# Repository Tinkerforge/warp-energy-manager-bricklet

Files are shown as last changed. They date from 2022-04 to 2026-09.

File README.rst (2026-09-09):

WARP Energy Manager Bricklet
============================

This Bricklet together with the ESP32 Ethernet Brick form the
hardware used in the WARP Energy Manager.

See https://www.warp-charger.com/energy-manager.html for more details

This repository contains the firmware source code and the hardware design
files. The documentation generator configs can be found at
https://github.com/Tinkerforge/generators

.. BEGIN WARP REPOSITORIES (managed block, generated from esp32-firmware/repo_overview.rst - do not edit by hand, run update_repo_overview.py instead)

WARP Repositories
-----------------

This is an overview of all repositories that make up the WARP Charger and
WARP Energy Manager ecosystem.

Please report **any** issue concerning WARP hard- or software in the
`esp32-firmware`_ repository, no matter which repository it originates from.

Software
~~~~~~~~

- `esp32-firmware`_ - Source code of the ESP32 firmware shared between all WARP Chargers and Energy Managers

Libraries used by the firmware:

- `tfjson`_ - SAX style JSON serializer and deserializer
- `tfnetwork`_ - Modbus TCP server and client implementation
- `tfocpp`_ - OCPP 1.6 implementation
- `tftools`_ - Miscellaneous tools and helpers

Remote access:

- `esp32-remote-access`_ - Source code of the my.warp-charger.com remote access server

Documentation, tools and integrations:

- `warp-charger`_ - Source code of (docs.)warp-charger.com and the printed manual, released firmwares, datasheets and documents, as well as some tools and hardware design files
- `api.warp-charger.com`_ - Serves APIs that are used by WARP Chargers to obtain relevant public information like day ahead prices
- `vislog.warp-charger.com`_ - Visualizes WARP Charger logs and EVSE debug protocols
- `dbus-warp-charger`_ - Integrates WARP Chargers into a Victron Energy Venus OS device (e.g. Cerbo GX)

WARP Charger Hardware
~~~~~~~~~~~~~~~~~~~~~~

WARP4 Charger
"""""""""""""

*Current charger generation.*

- `warp-esp32-ethernet-v2-brick`_ - Hardware design files of the WARP ESP32 Ethernet Brick 2.0
- `warp-esp32-ethernet-v2-co-bricklet`_ - Firmware source code of the WARP ESP32 Ethernet 2.0 Co Bricklet (co-processor)
- `evse-v4-bricklet`_ - Hardware design files of the EVSE 4.0 Bricklet (firmware shared with the EVSE 2.0 Bricklet)
- `nfc-bricklet`_ - Firmware source code and hardware design files of the NFC Bricklet

WARP3 Charger
"""""""""""""

- `warp-esp32-ethernet-brick`_ - Hardware design files of the WARP ESP32 Ethernet Brick
- `evse-v3-bricklet`_ - Hardware design files of the EVSE 3.0 Bricklet (firmware shared with the EVSE 2.0 Bricklet)
- `nfc-bricklet`_ - Firmware source code and hardware design files of the NFC Bricklet

WARP2 Charger
"""""""""""""

- `esp32-ethernet-brick`_ - Hardware design files of the ESP32 Ethernet Brick
- `evse-v2-bricklet`_ - Firmware source code and hardware design files of the EVSE 2.0 Bricklet
- `nfc-bricklet`_ - Firmware source code and hardware design files of the NFC Bricklet

WARP1 Charger
"""""""""""""

- `esp32-brick`_ - Hardware design files of the ESP32 Brick
- `evse-bricklet`_ - Firmware source code and hardware design files of the EVSE Bricklet
- `rs485-bricklet`_ - Firmware source code and hardware design files of the RS485 Bricklet

WARP Energy Manager Hardware
~~~~~~~~~~~~~~~~~~~~~~~~~~~~~~

WARP Energy Manager 2.0
"""""""""""""""""""""""

*Current energy manager generation.*

- `esp32-ethernet-brick`_ - Hardware design files of the ESP32 Ethernet Brick
- `warp-energy-manager-v2-bricklet`_ - Firmware source code and hardware design files of the WARP Energy Manager 2.0 Bricklet
- `warp-front-panel-bricklet`_ - Firmware source code and hardware design files of the WARP Front Panel Bricklet

WARP Energy Manager 1.0
"""""""""""""""""""""""

- `esp32-ethernet-brick`_ - Hardware design files of the ESP32 Ethernet Brick
- `warp-energy-manager-bricklet`_ - Firmware source code and hardware design files of the WARP Energy Manager Bricklet

Forked/patched projects
~~~~~~~~~~~~~~~~~~~~~~~~~

- `arduino-esp32`_
- `esp32-arduino-libs`_
- `WireGuard-ESP32-Arduino`_

.. Link targets: One definition per repository, keep in sync with the lists above.

.. _esp32-firmware: https://github.com/Tinkerforge/esp32-firmware
.. _tfjson: https://github.com/Tinkerforge/tfjson
.. _tfnetwork: https://github.com/Tinkerforge/tfnetwork
.. _tfocpp: https://github.com/Tinkerforge/tfocpp
.. _tftools: https://github.com/Tinkerforge/tftools
.. _esp32-remote-access: https://github.com/Tinkerforge/esp32-remote-access
.. _warp-charger: https://github.com/Tinkerforge/warp-charger
.. _api.warp-charger.com: https://github.com/Tinkerforge/api.warp-charger.com
.. _vislog.warp-charger.com: https://github.com/Tinkerforge/vislog.warp-charger.com
.. _dbus-warp-charger: https://github.com/Tinkerforge/dbus-warp-charger
.. _warp-esp32-ethernet-v2-brick: https://github.com/Tinkerforge/warp-esp32-ethernet-v2-brick
.. _warp-esp32-ethernet-v2-co-bricklet: https://github.com/Tinkerforge/warp-esp32-ethernet-v2-co-bricklet
.. _evse-v4-bricklet: https://github.com/Tinkerforge/evse-v4-bricklet
.. _nfc-bricklet: https://github.com/Tinkerforge/nfc-bricklet
.. _warp-esp32-ethernet-brick: https://github.com/Tinkerforge/warp-esp32-ethernet-brick
.. _evse-v3-bricklet: https://github.com/Tinkerforge/evse-v3-bricklet
.. _esp32-ethernet-brick: https://github.com/Tinkerforge/esp32-ethernet-brick
.. _evse-v2-bricklet: https://github.com/Tinkerforge/evse-v2-bricklet
.. _esp32-brick: https://github.com/Tinkerforge/esp32-brick
.. _evse-bricklet: https://github.com/Tinkerforge/evse-bricklet
.. _rs485-bricklet: https://github.com/Tinkerforge/rs485-bricklet
.. _warp-energy-manager-v2-bricklet: https://github.com/Tinkerforge/warp-energy-manager-v2-bricklet
.. _warp-front-panel-bricklet: https://github.com/Tinkerforge/warp-front-panel-bricklet
.. _warp-energy-manager-bricklet: https://github.com/Tinkerforge/warp-energy-manager-bricklet
.. _arduino-esp32: https://github.com/Tinkerforge/arduino-esp32
.. _esp32-arduino-libs: https://github.com/Tinkerforge/esp32-arduino-libs
.. _WireGuard-ESP32-Arduino: https://github.com/Tinkerforge/WireGuard-ESP32-Arduino

.. END WARP REPOSITORIES

Repository Content
------------------

software/:
 * examples/: Examples for all supported languages
 * build/: Compiled files
 * src/: Source code of firmware
 * Makefile: Makefile to build project

hardware/:
 * Contains KiCad project files and additionally schematics as PDF

datasheets/:
 * Contains datasheets for sensors and complex ICs that are used

Hardware
--------

The hardware is designed with the open source EDA Suite KiCad
(http://www.kicad.org). Before you are able to open the files,
you have to install the Tinkerforge kicad-libraries
(https://github.com/Tinkerforge/kicad-libraries). You can either clone
them directly in hardware/ or clone them in a separate folder and
symlink them into hardware/
(ln -s kicad_path/kicad-libraries project_path/hardware). After that you
can open the .pro file in hardware/ with KiCad and from there view and
modify the schematics and the PCB layout.

Software
--------

If you want to do your own Brick/Bricklet firmware development we highly
recommend that you use our build environment setup script and read the
tutorial (https://www.tinkerforge.com/en/doc/Tutorials/Tutorial_Build_Environment/Tutorial.html).

To compile the C code we recommend you to install the newest GNU Arm Embedded
Toolchain (https://launchpad.net/gcc-arm-embedded/+download).
You also need to install bricklib2 (https://github.com/Tinkerforge/bricklib2).

You can either clone it directly in software/src/ or clone it in a
separate folder and symlink it into software/src/
(ln -s bricklib_path/bricklib2 project_path/software/src/). Finally make sure to
have CMake installed (http://www.cmake.org/cmake/resources/software.html).

After that you can build the firmware by invoking make in software/.
The firmware (.zbin) can then be found in software/build/ and uploaded
with brickv (click button "Flashing" on start screen).

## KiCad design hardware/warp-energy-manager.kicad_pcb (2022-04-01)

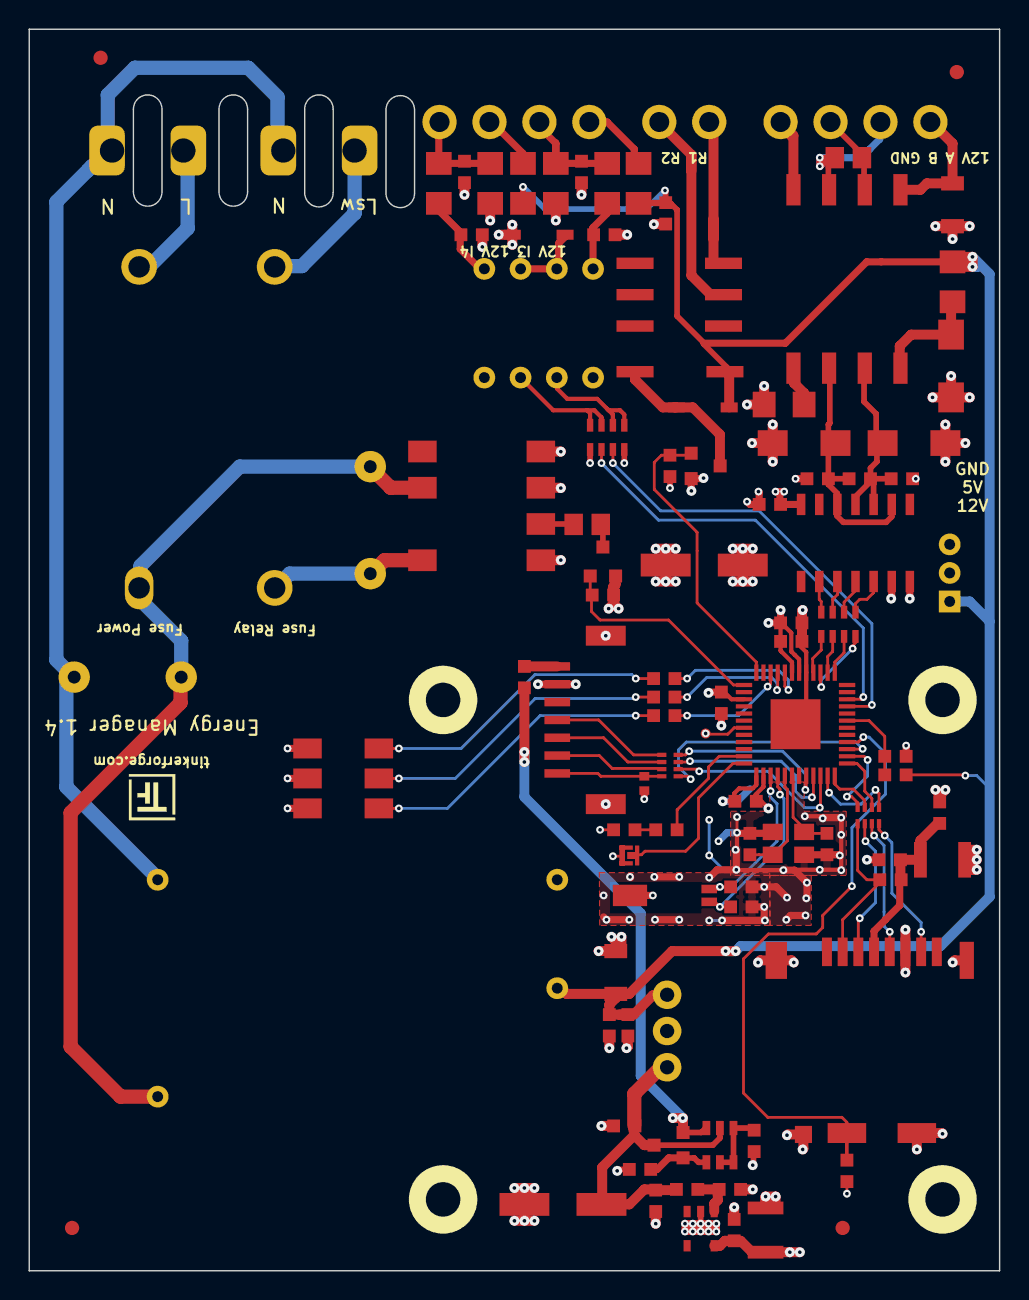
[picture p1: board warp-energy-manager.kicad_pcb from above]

Board: 4 copper layers, 68.0 x 87.0 mm, 104 parts (0 on the bottom side), 81 nets.

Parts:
A101, A102, A103, A104: DRILL; DRILL_NP_35
C101: 220pF; C0402F
C102, C104, C107, C112, C113, C114, C117, C127, C130, C132: 100nF; C0603F
C103, C106, C124, C125, C126: 1uF; C0603F
C105, C115: 4.7uF/50V; C1206
C108, C109: 100uF; ELKO_63
C110: 2.2uF; C0603F
C111, C116: 100uF; C1210
C118, C119: 15pF; C0603F
C128, C129: 10pF; C0603F
C131: 220nF; C0603F
D101: CLP6C-FKB-CK1P1G1BB7R3R3; PLCC6-6x5
D102, D106, D111: SMAJ12CA; DO-214AC
D103: blue; D0603F
D105, D107: B0520LW-7; SOD-123
F101, F102: FUSE; Fuse-Holder-5x20
Fiducial_Mark: VAL**; Fiducial_Mark
Fiducial_Mark#2, Fiducial_Mark#3, Fiducial_Mark#4: VAL**; Fiducial_Mark
J101: Boot; SolderJumper
J102: DM3CS; SD-Card-DM3CS
L101, L102, L103: FB; R0603F
L104: WE-SL
P101: CON-SENSOR2; CON-SENSOR2_180
P102: Relay; OQ_2P_5mm_230V
P103: L+N; OQ_2P_5mm_230V
P104: OUT; OQ_2P
P105: INPUT; OQ_4P
P106: DNP; JST-PH-3-THT
P110: MODBUS; OQ_4P
P111: Debug; DEBUG_PAD
PTC101, PTC102: PTC 0.45A; R1206E
Q102: SI2305CDS-T1-GE3; SOT23GDS
Q103: 2N7002P; SOT23GDS
Q105: SSM3J355R,LF; SOT23GDS
R101, R102: 51; R0603F
R103: 100; R0603F
R104, R105, R111, R112, R116, R117: 1k; R1206E
R106, R109, R140: 10k; R0603F
R107: 300k; R0603F
R108: 100k; R0603F
R113, R128: MOV-10D391KTR; VAR_10mm
R114, R137: 120; R0805E
R115, R118, R124: 1k; R0603F
R133: 47k; R0603F
R134, R136: 750; R0603F
R135: DNP; R0603F
REL101: AGQ200S12Z; AGQ2X0
RP101, RP103: 82; 4X0402
RP102: 10k; 0603X4
RP105: 10k; 4X0603
U101: XMC1404; QFN48-EP2
U103: DMMT5401; SOT26
U108: AQH3213AX; AQ-H
U109: HCPL2731; DIP-8
U110: TPS70933DBVR; SOT23-5
U111: IRM02-12; IRM02
U112: WPMDL110
U113: SP3491; SOIC-14_3.9x8.7mm_Pitch1.27mm
X101: 16MHz; CRYSTAL_3225
X102: 32.768kHz; AB26TRQ

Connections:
3V3: C102.1, C109.1, C110.1, C111.1, C127.1, C130.1, C131.1, C132.2, D101.1, D101.2, D101.3, D103.1, L102.2, Q102.S, R106.2, R115.2, R134.1, RP105.1, RP105.4, U101.18, U101.19, U101.27, U101.38, U109.8, U110.5, U113.14
5V: C103.1, C108.1, C126.1, L101.2, P106.2, Q105.D, U103.5, U112.3
485-D: RP102.4, U101.15
485-DE: RP102.3, U101.13
485-R: RP102.1, U101.16
485-~REB: RP102.2, U101.14
BOOT: J101.2, U101.36
GND: C101.2, C102.2, C103.2, C104.2, C105.2, C106.2, C107.2, C108.2, C109.2, C110.2, C111.2, C112.2, C113.1, C114.2, C115.1, C116.2, C117.2, C118.1, C119.1, C124.2, C125.2, C126.2, C127.2, C128.2, C129.2, C130.2, C131.2, C132.1, D102.1, D105.2, D106.2, D111.2, J101.1, J102.6, J102.S, P101.2, P101.EP, P106.3, PTC101.2, Q103.S, R104.2, R105.2, R108.1, R118.1, R133.1, R136.2, R140.1, U101.17, U101.37, U101.EP, U108.1, U108.3, U108.4, U109.5, U110.2, U111.4, U112.2, U113.6, U113.7, X101.3, X102.3
IN0: RP105.2, U101.9
IN1: RP105.3, U101.10
L: F101.2, R113.2, R128.1, U108.6, U111.1
N: P102.2, P103.2, R128.2, U111.2
unnamed: C101.1, P101.7, RP101.4
unnamed: C104.1, P105.2, R104.1, R112.1
unnamed: C106.1, L101.1, U110.1
unnamed: C107.1, P105.4, R105.1, R117.1
unnamed: C112.1, R117.2, U109.4
unnamed: C114.1, R112.2, U109.1
unnamed: C115.2, L104.5, P110.1
unnamed: C116.1, C117.1, J102.4, L102.1, R109.2
unnamed: C128.1, U101.41, X101.2
unnamed: C129.1, U101.42, X101.1
unnamed: D101.4, R101.1
unnamed: D101.5, R102.1
unnamed: D101.6, R103.1
unnamed: D102.2, L104.4, PTC102.2
unnamed: D103.2, R124.2
unnamed: D105.1, U109.2, U109.3
unnamed: D106.1, L104.3, R135.2, R136.1, U113.10, U113.11
unnamed: D107.1, Q103.D, REL101.8
unnamed: D111.1, L104.2, R134.2, R135.1, U113.9, U113.12
unnamed: F101.1, P103.1
unnamed: F102.1, P102.1
unnamed: F102.2, R113.1, U108.8
unnamed: J102.2, R109.1, RP103.1
unnamed: J102.3, RP103.2
unnamed: J102.5, RP103.3
unnamed: J102.7, RP103.4
unnamed: L103.1, Q105.S, U103.6
unnamed: L103.2, P101.1
unnamed: L104.1, PTC101.1
unnamed: L104.6, P110.3, R137.1
unnamed: L104.7, P110.2, R137.2
unnamed: L104.8, P110.4
unnamed: P101.4, RP101.1
unnamed: P101.5, RP101.2
unnamed: P101.6, RP101.3
unnamed: P104.1, REL101.4
unnamed: P104.2, REL101.3
unnamed: P105.1, R111.1
unnamed: P105.3, R116.1
unnamed: P111.1, U101.31
unnamed: Q102.D, R114.1
unnamed: Q105.G, R133.2, U103.1
unnamed: R101.2, U101.22
unnamed: R102.2, U101.21
unnamed: R103.2, U101.20
unnamed: R114.2, U108.2
unnamed: R124.1, U101.35
unnamed: R140.2, U103.2, U103.3, U103.4
unnamed: RP102.5, U113.5
unnamed: RP102.6, U113.4
unnamed: RP102.7, U113.3
unnamed: RP102.8, U113.2
unnamed: RP105.5, RP105.6, U109.6
unnamed: RP105.7, RP105.8, U109.7
OUT: Q103.G, R118.2, U101.24
RELAY: Q102.G, R115.1, U101.25
RTC-XTAL1: C119.2, U101.39, X102.2
RTC-XTAL2: C118.2, U101.40, X102.1
S-CLK: RP101.7, U101.45
S-CS: RP101.8, U101.44
S-MISO: RP101.5, U101.3
S-MOSI: RP101.6, U101.46
SD-CDS: J102.CDS, R106.1, U101.4
SD-CLK: RP103.6, U101.1
SD-CS: RP103.8, U101.2
SD-MISO: RP103.5, U101.47
SD-MOSI: RP103.7, U101.48
V12: R107.1, R108.2, U101.7
VCC: C105.1, C113.2, C124.1, C125.1, D107.2, P106.1, PTC102.1, R107.2, R111.2, R116.2, REL101.1, U111.3, U112.1

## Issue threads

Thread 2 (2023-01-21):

Include evcc in energy manager

m1lk0, 2023-01-21:
I am not sure about the specs of the warp energy manager while missing some options in warp charger (e.g. time/energy based charging). Tinkerforge themself propose https://evcc.io/
Would it be possible to include evcc.io in the energy manager?

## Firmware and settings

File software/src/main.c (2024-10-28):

/* warp-energy-manager-bricklet
 * Copyright (C) 2021 Olaf Lüke <olaf@tinkerforge.com>
 *
 * main.c: Initialization for WARP Energy Manager Bricklet
 *
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
 * You should have received a copy of the GNU Lesser General Public
 * License along with this library; if not, write to the
 * Free Software Foundation, Inc., 59 Temple Place - Suite 330,
 * Boston, MA 02111-1307, USA.
 */

#include <stdio.h>
#include <stdbool.h>

#include "configs/config.h"

#include "bricklib2/warp/rs485.h"
#include "bricklib2/warp/meter.h"
#include "bricklib2/bootloader/bootloader.h"
#include "bricklib2/hal/system_timer/system_timer.h"
#include "bricklib2/logging/logging.h"
#include "communication.h"

#include "io.h"
#include "led.h"
#include "voltage.h"
#include "eeprom.h"
#include "date_time.h"
#include "sd.h"
#include "data_storage.h"

int main(void) {
	logging_init();
	logd("Start WARP Energy Manager Bricklet\n\r");

	communication_init();
	io_init();
	led_init();
	rs485_init();
	meter_init();
	voltage_init();
	eeprom_init();
	date_time_init();
	data_storage_init();
	sd_init();

	while(true) {
		bootloader_tick();
		communication_tick();
		io_tick();
		led_tick();
		rs485_tick();
		meter_tick();
		voltage_tick();
		date_time_tick();
		sd_tick();
		data_storage_tick();
	}
}

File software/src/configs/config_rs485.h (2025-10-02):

/* warp-energy-manager-bricklet
 * Copyright (C) 2021 Olaf Lüke <olaf@tinkerforge.com>
 *
 * config_rs485.h: RS485 communication config
 *
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
 * You should have received a copy of the GNU Lesser General Public
 * License along with this library; if not, write to the
 * Free Software Foundation, Inc., 59 Temple Place - Suite 330,
 * Boston, MA 02111-1307, USA.
 */

#ifndef CONFIG_RS485_H
#define CONFIG_RS485_H

#include "xmc_common.h"
#include "xmc_gpio.h"
#include "xmc_uart.h"
#include "xmc_scu.h"

#define RS485_USIC_CHANNEL        USIC1_CH1
#define RS485_USIC                XMC_UART1_CH1

#define RS485_RX_PIN              P2_13
#define RS485_RX_INPUT            XMC_UART_CH_INPUT_RXD // UART input stage DX0
#define RS485_RX_SOURCE           0b011 // DX0D

#define RS485_TX_PIN              P2_12
#define RS485_TX_PIN_AF           (XMC_GPIO_MODE_OUTPUT_PUSH_PULL_ALT7 | P2_12_AF_U1C1_DOUT0)

#define RS485_NRXE_PIN            P2_11
#define RS485_TXE_PIN             P2_10

#define RS485_NRXE_AND_TXE_PORT   XMC_GPIO_PORT2
#define RS485_NRXE_PIN_NUM        11
#define RS485_TXE_PIN_NUM         10

#define RS485_SERVICE_REQUEST_RX  0  // receive
#define RS485_SERVICE_REQUEST_TX  1  // transfer
#define RS485_SERVICE_REQUEST_TFF 4  // transfer frame finished
#define RS485_SERVICE_REQUEST_RXA 5  // alternate receive (parity error)

// Make sure that the priorities are as follows
// RX > TX = TFF
// TFF should never displace TX. TFF is unnecessary if we are in TX IRQ
// TX should never displace TFF. This would be a race condition
// RX interrupt will never be issued if TXE is set. If we are receiving a message,
// TX should never interrupt RX (we would lose data in this case)
// For full-duplex there is no TFF and RX should be higher priority then TX
#define RS485_IRQ_RX              9
#define RS485_IRQ_RX_PRIORITY     2
#define RS485_IRQCTRL_RX          XMC_SCU_IRQCTRL_USIC1_SR0_IRQ9

#define RS485_IRQ_TX              10
#define RS485_IRQ_TX_PRIORITY     3
#define RS485_IRQCTRL_TX          XMC_SCU_IRQCTRL_USIC1_SR1_IRQ10

#define RS485_IRQ_TFF             13
#define RS485_IRQ_TFF_PRIORITY    3
#define RS485_IRQCTRL_TFF         XMC_SCU_IRQCTRL_USIC1_SR4_IRQ13

#define RS485_IRQ_RXA             14
#define RS485_IRQ_RXA_PRIORITY    2
#define RS485_IRQCTRL_RXA         XMC_SCU_IRQCTRL_USIC1_SR5_IRQ14


#define RS485_RX_HANDLER     IRQ_Hdlr_9
#define RS485_RX_FIFO_POS    32
#define RS485_RX_FIFO_LENGTH XMC_USIC_CH_FIFO_SIZE_16WORDS
#define RS485_RX_FIFO_LIMIT  8
#define RS485_TX_HANDLER     IRQ_Hdlr_10
#define RS485_TX_FIFO_POS    48
#define RS485_TX_FIFO_LENGTH XMC_USIC_CH_FIFO_SIZE_16WORDS
#define RS485_TX_FIFO_LIMIT  8
#define RS485_BUFFER_SIZE    (512*2)


#endif

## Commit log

2021-10-11 add hardware files
    [warp-energy-manager.kicad_pcb, warp-energy-manager.sch]
2021-10-12 changed info box
    [warp-energy-manager.kicad_pcb]
2021-10-12 changed RS485 resistors
    [warp-energy-manager.kicad_pcb, warp-energy-manager.sch]
2021-10-13 Add initial stub firmware implementation
    [cmake_config_custom.txt]
2021-10-13 Add drivers for IO, SDM630 and input voltage
2021-10-13 version 1.1
    * fix relay pinning
    * fix ac/dc power supply position
    [warp-energy-manager.kicad_pcb, warp-energy-manager.sch]
2021-10-25 Update KiCad link
    https://www.kicad.org/blog/2021/10/Avoid-links-to-former-kicad-domain/
2021-11-02 enlarged esp holes
    [warp-energy-manager.kicad_pcb]
2021-11-04 finish version 1.2
    * move elko
    * change rs485 resistors
    * design improvements
    [warp-energy-manager.kicad_pcb, warp-energy-manager.sch]
2021-12-16 add version 1.3
    * add 12V output for rs485
    * change protection diodes type
    [warp-energy-manager.kicad_pcb, warp-energy-manager.sch]
2021-12-17 drc check
    [warp-energy-manager.kicad_pcb]
2022-01-18 generate production version
    add fiducials
    [warp-energy-manager.kicad_pcb, warp-energy-manager.sch]
2022-03-23 add version 1.4
    add micro sd card socket
    [warp-energy-manager.kicad_pcb, warp-energy-manager.sch]
2022-03-24 add 32.768kHz crystal for rtc
    [warp-energy-manager.kicad_pcb, warp-energy-manager.sch]
2022-03-24 specify rtc capacitors
    [warp-energy-manager.kicad_pcb, warp-energy-manager.sch]
2022-04-01 fix routing
    [warp-energy-manager.kicad_pcb]
2022-08-10 Add charger simulator and tester ui
2022-12-16 Implement new charge manager protocol in simulator.
2022-12-22 Fix active high/low mixup
    [io.c]
2022-12-23 simulator: Report CP disconnect feature, fix zero meter values.
    - Report support for CP disconnect to manager.
    - Make current allocated by manager available to simulator.
    - Fix default value being used in meter simulator when power should be zero.
2023-01-16 Remove fatfs and DAVE implementation for SPI/FATFS/RTC
2023-01-16 Add initial sd card support with littlefs testing
    We switched from fatfs and the DAVE sdmmc implementation from
    Infineon to our own sdmmc implementation and littlefs.
    The Infineon lib was not stable and to complex to debug...
    Note: Littlefs currently consists of testing code, this is
    still WIP
2023-01-30 Use coop task and fifo/interrupts for more efficient sdmmc handling
2023-01-30 Change contactor check pin to active low
2023-02-20 Add support for Set/GetDateTime
    TODO: In date_time init we still need to check if the time is already
    set and not re-set it in this case.
2023-02-24 move to kicad6
    [warp-energy-manager.kicad_sch, warp-energy-manager.sch]
2023-02-27 Add lfs filesystem mount script
2023-03-02 Change version back to 2.0.0 and change flash from 64kb to 200kb
    We had a big fuckup and released firmwares with max 64kb flash
    while we have a mcu with 200kb flash. The old firmwares are incompatible
    because of CRC at end of flash.
    [cmake_config_custom.txt]
2023-03-07 Add support for new LEDState-API
    Blinking and Breathing is based on the same timing as the WARP Charger LED
    [communication.h, led.c]
2023-03-09 Add orange LED blinking if connection lost
2023-03-21 Check if config is set for external 32.768 kHz crystal
    We had a bug in early bootloader versions that did not set it correctly,
    so we re-set it in this case in the date_time_init function
2023-06-15 Move meter functionality bricklib2/warp
    This is now shares wid EVESE Bricklet 2.0
    [config_rs485.h, main.c]
2023-08-14 Increase LED connection lost time to 15s and use during start-up.
    The WEM Brick takes at least 10s to start after a power-on reset,
    so give it 15s to avoid confusing users with orange blinking
    because of an expected delay.
    [led.c]
2023-10-27 Change "fast read" meter values to power and current per phase
2023-12-08 Add support for resetable relative import/export energy
    [communication.h]
2024-06-05 Prepare to add math support (not used currently)
2024-09-02 Move EEPROM and voltage code to bricklib
2024-09-13 Move detect pin definition to config_sdmmc.h
    It was in the sd.h before, but that one is shared between
    WEM1 and WEM2 now.
2024-09-19 Fix cb sizes (new sizes because of price data)
    [communication.h]
2025-09-16 Rename MeterRegisterType to use the same name as in esp32 firmware
2025-10-02 Fix -Wextra warnings and add new warning flags introduced in EVSE V2
    [config_rs485.h, config_sdmmc.h]

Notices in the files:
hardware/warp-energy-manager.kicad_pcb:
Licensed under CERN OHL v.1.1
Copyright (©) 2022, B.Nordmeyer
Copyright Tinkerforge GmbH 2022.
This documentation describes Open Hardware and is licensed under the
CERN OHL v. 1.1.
